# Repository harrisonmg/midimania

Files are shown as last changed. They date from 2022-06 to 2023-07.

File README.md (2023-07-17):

# A Custom MIDI Controller Design



## Mechanical
* Designed in [Onshape Free](https://www.onshape.com/en/products/free)
* 8 beatmania IIDX clone switches w/ LEDs from AliExpress
* 4 rotary potentiometers and 4 slide potentiometers
* Faceplate laser cut on 1/8" 5052 aluminum by [SendCutSend](https://sendcutsend.com/)
* Using aluminum wall mount sign holders with rubber pads as legs

## Electrical
* Based around a [Teensy 3.2](https://www.pjrc.com/store/teensy32.html) because I had one
* Connected via PCB and 18 gauge copper jewelry wire
* Switches wired inline with LEDs to light up when pressed
* PCB designed in [KiCad](https://www.kicad.org/)
* PCB manufactured by [Oshpark](https://oshpark.com/)
* NGE artwork desgined in [Inkscape](https://inkscape.org/)
* Art converted to footprints with [svg2mod](https://github.com/svg2mod/svg2mod)
* Special thanks to [Uri Shaked's Practical Guide to Designing PCB Art](https://blog.wokwi.com/a-practical-guide-to-designing-pcb-art/)

## Software
* Running Arduino
* Using [USB MIDI](https://www.pjrc.com/teensy/td_midi.html#:~:text=When%20you%20select%20%22MIDI%22%20from,3.0%20to%203.6%20are%20supported.)

## Bill of Materials
|Part|Price|
|---|---|
|[PCB](https://oshpark.com/)|$51.65|
|[Laser Cut Aluminum Faceplate](https://sendcutsend.com/)|$39.15|
|[Switch (8x)](https://www.aliexpress.com/item/2251832160522560.html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)|$24.99|
|[Teensy 3.2](https://www.pjrc.com/store/teensy32.html)|$19.80|
|[Aluminum Legs (10x)](https://www.amazon.com/gp/product/B07R1SLTY6/ref=ppx_yo_dt_b_search_asin_title?ie=UTF8&psc=1)|$13.99|
|[Jewlery Wire (55ft)](https://www.amazon.com/gp/product/B086VH27KM/ref=ppx_yo_dt_b_search_asin_title?ie=UTF8&th=1)|$12.99|
|[Slide Potentiometer Screws (10x)](https://www.mcmaster.com/97763A407/)|$8.67|
|[Rotary Potentiometer](https://www.adafruit.com/product/5280)|$7.80 ($1.95 ea)|
|[Slide Potentiometer](https://www.adafruit.com/product/4272)|$7.80 ($1.95 ea)|
|[Rubber Foot Pads (50x)](https://www.amazon.com/dp/B01LDLJF5K?psc=1&ref=ppx_yo2ov_dt_b_product_details)|$7.79|
|[1k Through-hole Resistor (100x)](https://www.amazon.com/dp/B07HDDWFDD?ref=ppx_yo2ov_dt_b_product_details&th=1)|$4.99|
|[Potentiometer Knobs (20x)](https://www.ebay.com/itm/192481232352)|$4.73|
|[Slide Potentiometer Knobs (10x)](https://www.ebay.com/itm/384835783660)|$2.45|
|TOTAL|$206.80 (yikes)|

## Build Notes

Everything fit in the plate beautifully. The faceplate only needed a little bit of post-processing with a file and some scotch brite.



The rotary potentiometer pins were longer than expected. I extended each slide potentiometer pin with the metal innard of a female pin header so that the PCB will sit parallel to the faceplate.



The aluminum legs strip easily.



The PCBs look great. There's a few spots where the silkscreen wasn't printed. I knew the fab house would remove silkscreen on top of exposed copper, but it looks like they also remove silkscreen within a small radius around exposed copper. Also, some small lines on the left were left out of my Gerbers; I'm not sure how that happened.



The copper wiring was a pain. Removing the coating from the jewelry wire and trying to keep everything straight and sized correctly was tedious.

The easiest method I found to remove the coating was scraping with a razor blade. Fun-Tak was useful for securing things while soldering.

I could've benefitted from better modeling of the wiring ahead of time, and I should've used through-hole pads on the PCB for the wire.

In the future I might try to use thicker wire that holds it shape better. Since I still have a bunch of wire left over, I'll probably find a way to strip a large amount of it ahead of time. I think I'll also buy better solder.



This sketch I found in my notes is pretty much how each switch is wired.



Finally, the linear and rotary potentiometer knobs both needed some work. I bought rotary pots without knob splines because they seemed nicer (apart from that), so I just drilled out the knobs a big to fit on. The linear pots came with knobs, but I bought nicer ones that were way too tight. I shaved down the linear pot stems a bit with a razor blade and used some Fun-Tak to try and help them sit a bit higher and not scratch against the plate.

Both sets of knobs still rub on the plate a bit, I think 1/8" is probably the upper limit these parts are intended to be mounted through.

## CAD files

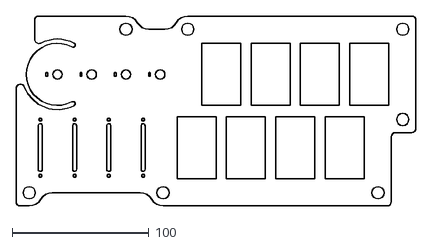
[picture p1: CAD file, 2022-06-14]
faceplate.DXF
291.9 x 138.6

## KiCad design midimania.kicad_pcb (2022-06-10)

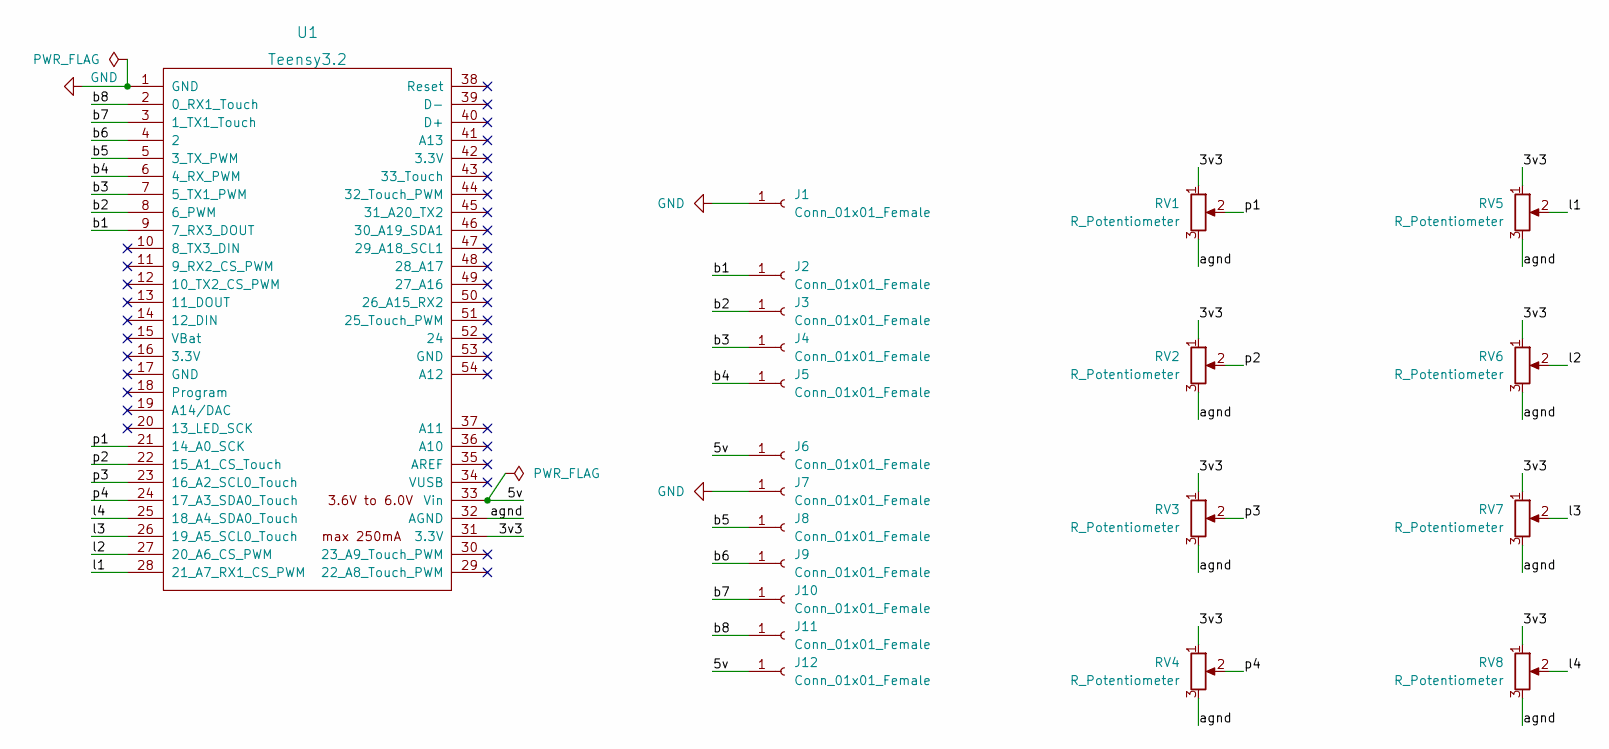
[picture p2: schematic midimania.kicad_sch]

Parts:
J1, J2, J3, J4, J5, J6, J7, J8, J9, J10, J11, J12: Conn_01x01_Female; TestPoint_Pad_1.5x1.5mm
RV1, RV2, RV3, RV4: R_Potentiometer; Potentiometer_Alpha_RV16AF-41
RV5, RV6, RV7, RV8: R_Potentiometer; Potentiometer_Slide_C3031N
U1: Teensy3.2; Teensy30_31_32_LC

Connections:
/3v3: RV1.1, RV2.1, RV3.1, RV4.1, RV5.1, RV6.1, RV7.1, RV8.1, U1.31 (3.3V)
/5v: J6.1, J12.1, U1.33 (Vin)
/agnd: RV1.3, RV2.3, RV3.3, RV4.3, RV5.3, RV6.3, RV7.3, RV8.3, U1.32 (AGND)
/b1: J2.1, U1.9 (7_RX3_DOUT)
/b2: J3.1, U1.8 (6_PWM)
/b3: J4.1, U1.7 (5_TX1_PWM)
/b4: J5.1, U1.6 (4_RX_PWM)
/b5: J8.1, U1.5 (3_TX_PWM)
/b6: J9.1, U1.4 (2)
/b7: J10.1, U1.3 (1_TX1_Touch)
/b8: J11.1, U1.2 (0_RX1_Touch)
/l1: RV5.2, U1.28 (21_A7_RX1_CS_PWM)
/l2: RV6.2, U1.27 (20_A6_CS_PWM)
/l3: RV7.2, U1.26 (19_A5_SCL0_Touch)
/l4: RV8.2, U1.25 (18_A4_SDA0_Touch)
/p1: RV1.2, U1.21 (14_A0_SCK)
/p2: RV2.2, U1.22 (15_A1_CS_Touch)
/p3: RV3.2, U1.23 (16_A2_SCL0_Touch)
/p4: RV4.2, U1.24 (17_A3_SDA0_Touch)
GND: J1.1, J7.1, U1.1 (GND)

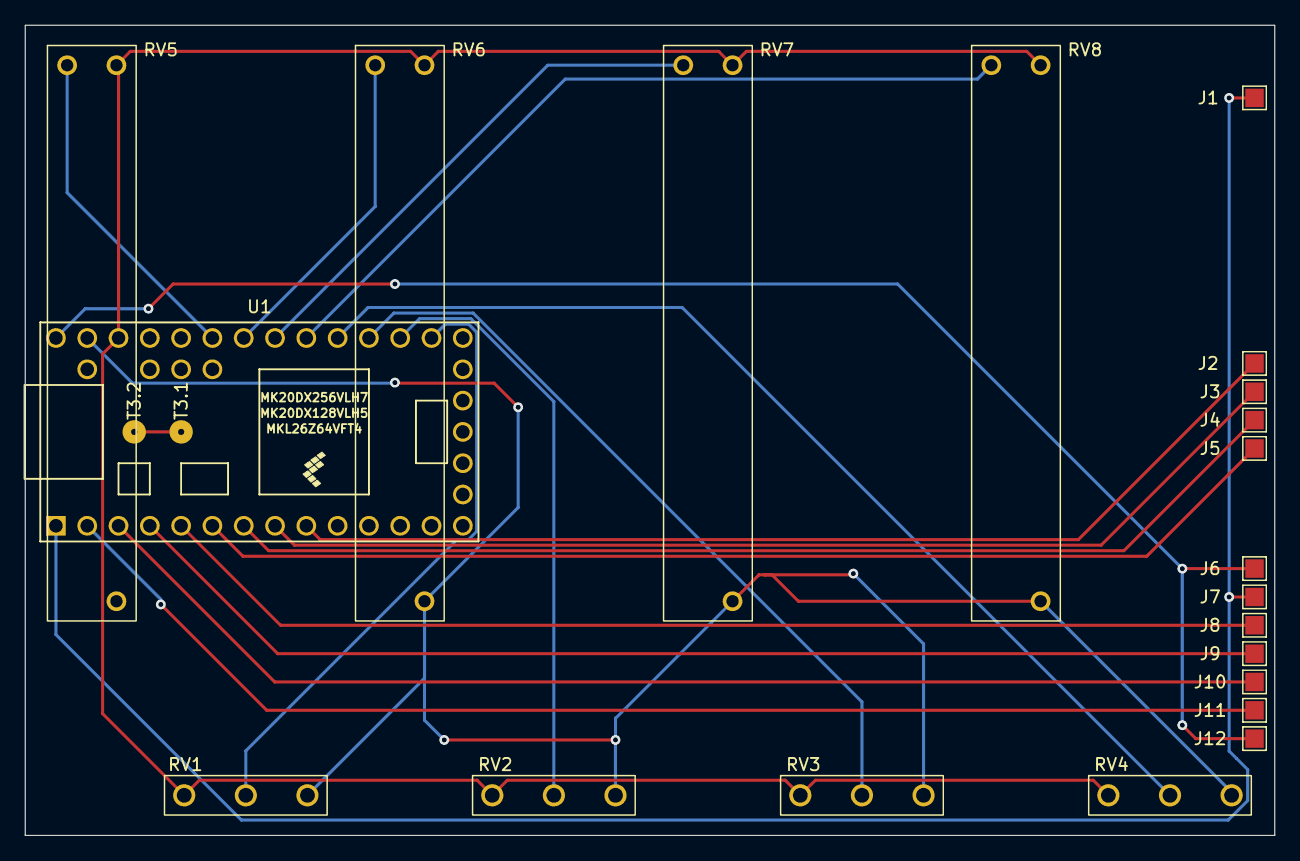
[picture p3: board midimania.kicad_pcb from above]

Board: 2 copper layers, 101.4 x 65.8 mm, 21 parts (0 on the bottom side), 20 nets.

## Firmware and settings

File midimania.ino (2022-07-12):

#include <ResponsiveAnalogRead.h>
#include <Bounce2.h>

const int channel = 1;          // MIDI channel
const int A_PINS = 8;           // number of Analog PINS
const int D_PINS = 8;           // number of Digital PINS
const int ON_VELOCITY = 99;     // note-on velocity sent from buttons (should be 65 to 127)

const int ANALOG_PINS[A_PINS] = {A0, A1, A2, A3, A4, A5, A6, A7};
const int CCID[A_PINS] = {21, 22, 23, 24, 25, 26, 27, 28};

const int DIGITAL_PINS[D_PINS] = {7, 6, 5, 4, 3, 2, 1, 0};
const int NOTES[D_PINS] = {60, 61, 62, 63, 64, 65, 66, 67};

const int BOUNCE_TIME = 5;  // ms
const int FADER_ZERO = 4;


byte data[A_PINS];
byte control_lag[A_PINS]; // when lag and new are not the same then update MIDI CC value

ResponsiveAnalogRead analog[] =
{
    {ANALOG_PINS[0], true},
    {ANALOG_PINS[1], true},
    {ANALOG_PINS[2], true},
    {ANALOG_PINS[3], true},
    {ANALOG_PINS[4], true},
    {ANALOG_PINS[5], true},
    {ANALOG_PINS[6], true},
    {ANALOG_PINS[7], true},
};

Bounce digital[] =
{
    Bounce(DIGITAL_PINS[0], BOUNCE_TIME),
    Bounce(DIGITAL_PINS[1], BOUNCE_TIME),
    Bounce(DIGITAL_PINS[2], BOUNCE_TIME),
    Bounce(DIGITAL_PINS[3], BOUNCE_TIME),
    Bounce(DIGITAL_PINS[4], BOUNCE_TIME),
    Bounce(DIGITAL_PINS[5], BOUNCE_TIME),
    Bounce(DIGITAL_PINS[6], BOUNCE_TIME),
    Bounce(DIGITAL_PINS[7], BOUNCE_TIME),
};

void setup()
{
    Serial.begin(9600);
    for (int i = 0; i < D_PINS; ++i)
        pinMode(DIGITAL_PINS[i], INPUT_PULLDOWN);
}

void loop()
{
    getAnalogData();
    getDigitalData();
    while (usbMIDI.read()) { /* ignore */ }
}

void getAnalogData()
{
    for (int i = 0; i < A_PINS; ++i)
    {
        analog[i].update();
        if(analog[i].hasChanged())
        {
            data[i] = analog[i].getValue() >> 3;

            // invert and handle fader deadzone
            int control = data[i];
            if (i < 4)
            {
                if (control <= FADER_ZERO)
                {
                    control = 0;
                }
                else if (127 - control <= FADER_ZERO)
                {
                    control = 127;
                }
            }

            control = 127 - control;

            if (i < 4)
            {
                Serial.println(control);
            }

            if (control != control_lag[i])
            {
                control_lag[i] = control;
                usbMIDI.sendControlChange(CCID[i], control, channel);
            }
        }
    }
}

void getDigitalData()
{
    for (int i = 0; i < D_PINS; i++)
    {
        digital[i].update();

        if (digital[i].risingEdge())
            usbMIDI.sendNoteOn(NOTES[i], ON_VELOCITY, channel);

        if (digital[i].fallingEdge())
            usbMIDI.sendNoteOff(NOTES[i], 0, channel);
    }
}

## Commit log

2022-06-14 pcb design
    [midimania-B_Cu.gbr, midimania-B_Mask.gbr, midimania-B_Paste.gbr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]
2022-06-14 added faceplate and README
    [faceplate.DXF]
2022-06-16 updated BOM
